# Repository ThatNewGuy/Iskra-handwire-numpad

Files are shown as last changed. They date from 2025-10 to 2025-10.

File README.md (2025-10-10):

## Iskra Handwired Numpad

### Overview
Iskra is a DIY 10‑key hand‑wired macropad designed for both wired USB and Bluetooth (ZMK) use. It uses low‑profile Kailh Choc switches and a Pro Micro nRF52840 (nice!nano v2 clone). The design is fully open source and supports ZMK Studio for easy keymap customization.

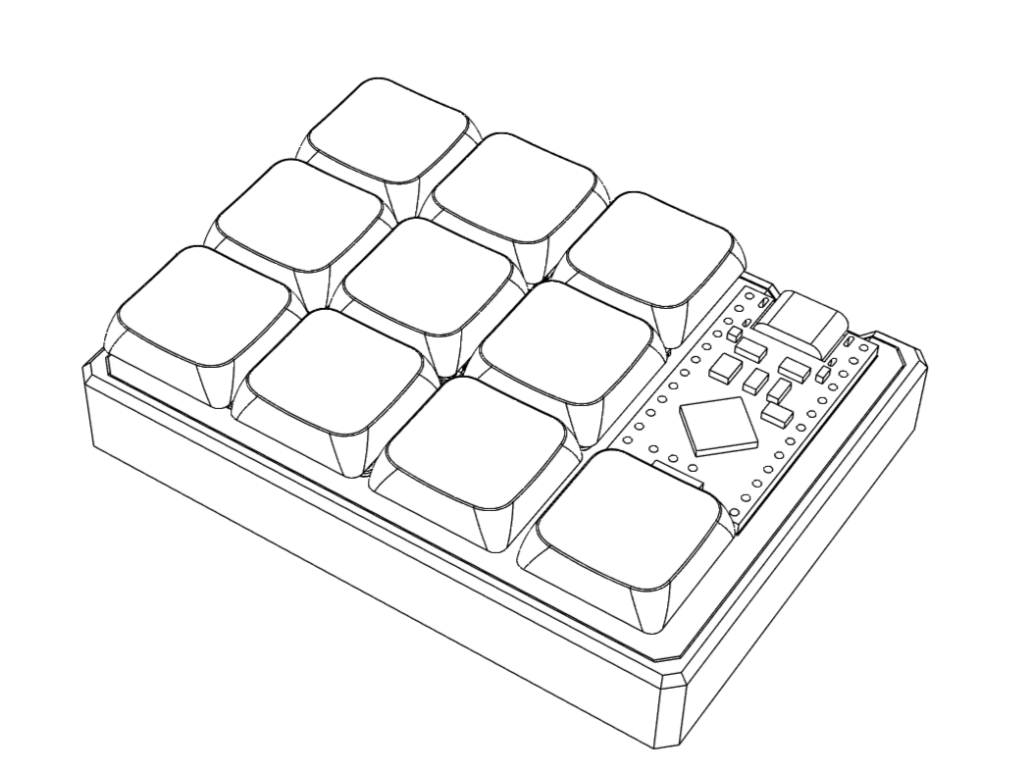
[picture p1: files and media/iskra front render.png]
Front render


#### Key features
- **3 programmable layers** (ZMK firmware)
- **Compact** credit‑card size layout (approx. 82 × 60 × 22 mm)
- **Hand‑wired** 3×4 matrix with 1N4148 diodes (10 keys populated)
- **Wired USB‑C** and **Bluetooth** modes
- **ZMK Studio** support for on‑device editing

### Real photos
<p>
  Home view
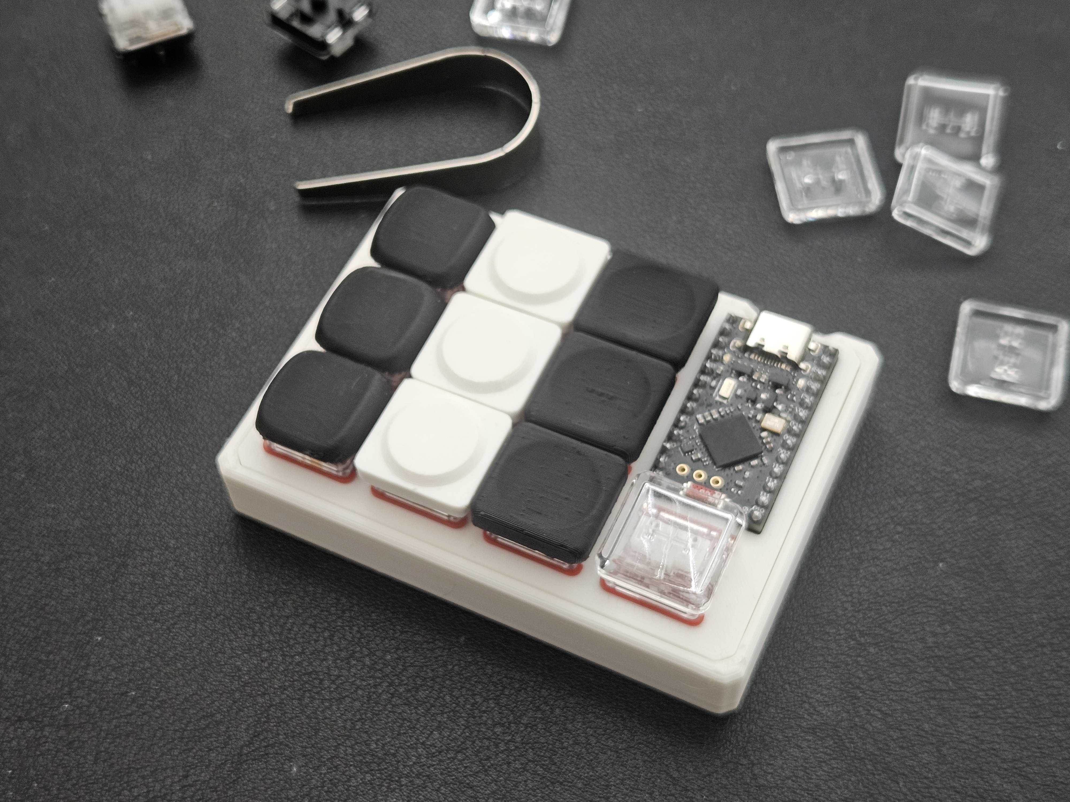
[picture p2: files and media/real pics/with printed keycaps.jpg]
With printed keycaps
  
</p>
<p>
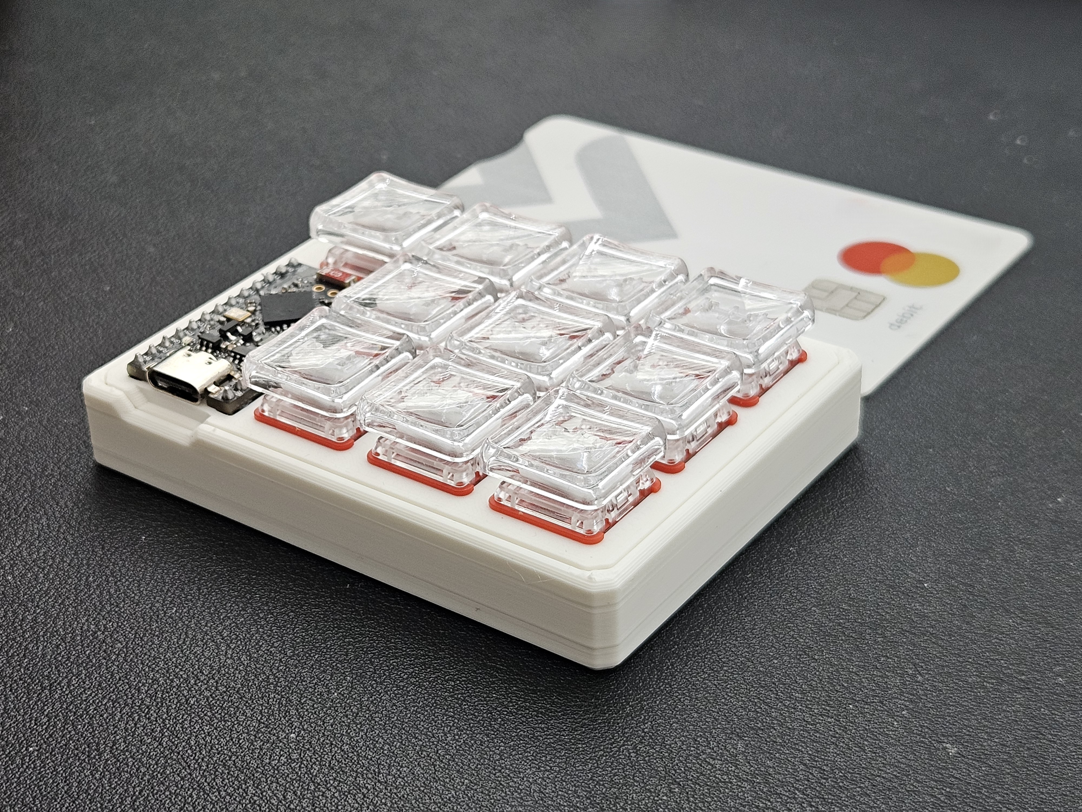
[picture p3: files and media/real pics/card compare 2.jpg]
Card compare 2
  
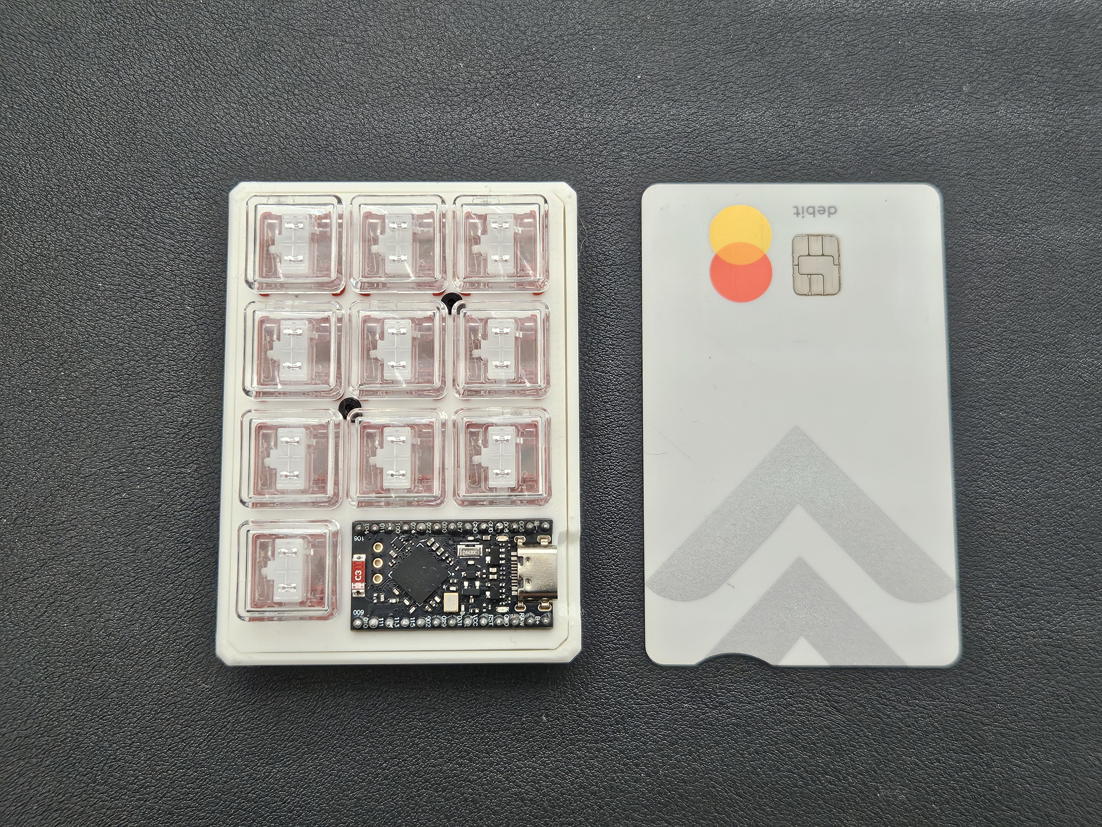
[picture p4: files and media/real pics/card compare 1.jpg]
Card compare 1
  
</p>

---

### Bill of Materials (BOM)

| Part | Qty | Price (EUR) | Link |
| --- | ---: | ---: | --- |
| Kailh Choc switches | 10 | 2.00 | [AliExpress](https://www.aliexpress.com/item/1005006626760418.html) |
| Pro Micro nRF52840 (nice!nano clone) | 1 | 3.80 | [AliExpress](https://www.aliexpress.com/item/1005007010555229.html) |
| M2 brass standoff, 6 mm | 2 | 0.20 | [AliExpress](https://www.aliexpress.com/item/1005006049595637.html) |
| M2 screw, 6 mm | 4 | 0.10 | [AliExpress](https://www.aliexpress.com/item/1005005070119421.html) |
| 1N4148 diodes | 10 | 0.13 | [AliExpress](https://www.aliexpress.com/item/1005006861038367.html) |
| Copper wire | 15 cm | 0.05 | [AliExpress](https://www.aliexpress.com/item/1005009078359338.html) |

Assumes you already have a soldering iron, solder, insulation/masking tape, and a few wires.

---

### Firmware
- Prebuilt firmware (drag‑and‑drop): `Firmware/Ready to flash firmware/iskra.uf2`
- Config source (ZMK): `Firmware/zmk-config-iskra`

#### How to flash (UF2)
1. Connect the numpad to the PC.
2. Short the `GND` and `RST` pins twice quickly (double‑tap reset).
3. A removable drive (e.g. “NICE NANO”) will appear.
4. Copy `iskra.uf2` into the drive.
5. It will restart; the numpad is now flashed.

Note: The prebuilt firmware assumes the same controller (nRF52840 nice!nano v2‑compatible) and the pin wiring specified below.

---

### Documentation
- [Build and wiring guide (PDF)](files%20and%20media/Iskra%20Numpad%20Build%20and%20wiring%20guide.pdf)
- [User manual (PDF)](files%20and%20media/Iskra%20Numpad,%20user%20manual.pdf)

 These documents provide a step‑by‑step reference for building a hand‑wired numpad: keyboard matrix wiring with **1N4148 diodes**, **Kailh Choc** low‑profile switches, and a **Pro Micro nRF52840** (nice!nano v2 clone). Topics include routing rows and columns, insulating wires to avoid shorts, mapping pins to firmware, flashing ZMK via **UF2**, configuring **Bluetooth** profiles, and using **ZMK Studio** to adjust keymaps.

---

### Layout, Layers, and Combos

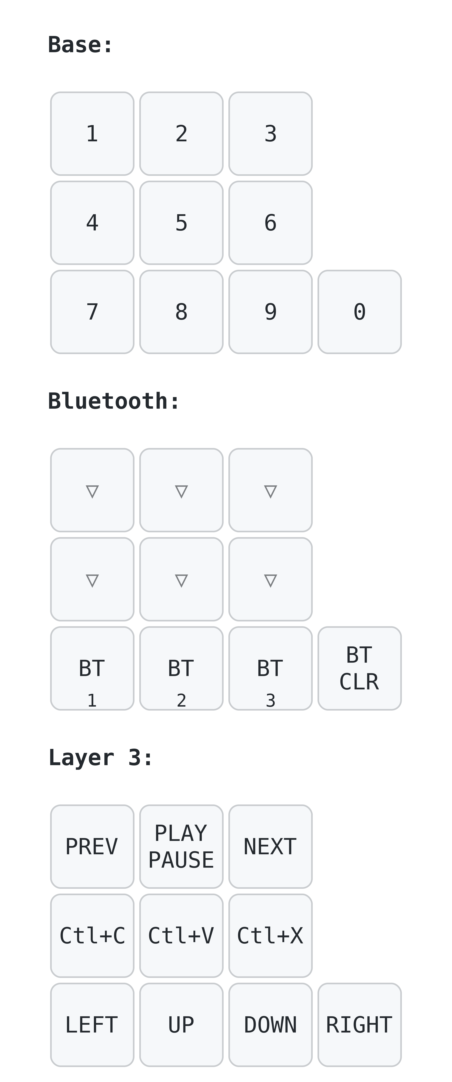
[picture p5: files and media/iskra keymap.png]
Keymap


#### Layers (from firmware config)
- **Base**: `1 2 3 / 4 5 6 / 7 8 9 0`
- **Bluetooth**: Bottom row provides Bluetooth controls — `BT_SEL 1`, `BT_SEL 2`, `BT_SEL 3`, `BT_CLR`; other keys are transparent.
- **Layer 3**: Media and navigation
  - Top row: Previous, Play/Pause, Next
  - Middle row: Ctrl+C, Ctrl+V, Ctrl+X
  - Bottom row: Arrow Left, Up, Down, Right

#### Combos
- **Base layer combo**: Press the top three keys at the same time → switches to Base
- **Bluetooth layer combo**: Press the middle three keys at the same time → switches to Bluetooth
- **Third layer combo**: Press the bottom three keys at the same time → switches to Layer 3
- **ZMK Studio unlock**: Press the top two keys at the same time

Combo visuals:

<p>
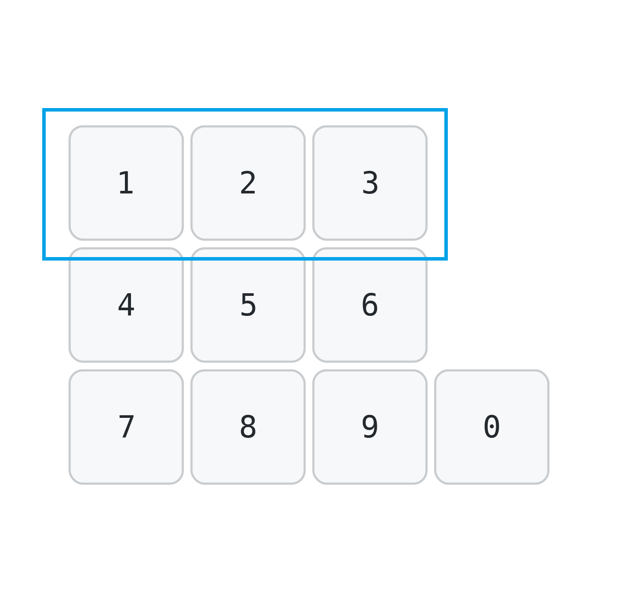
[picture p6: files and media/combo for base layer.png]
Combo for base layer
  
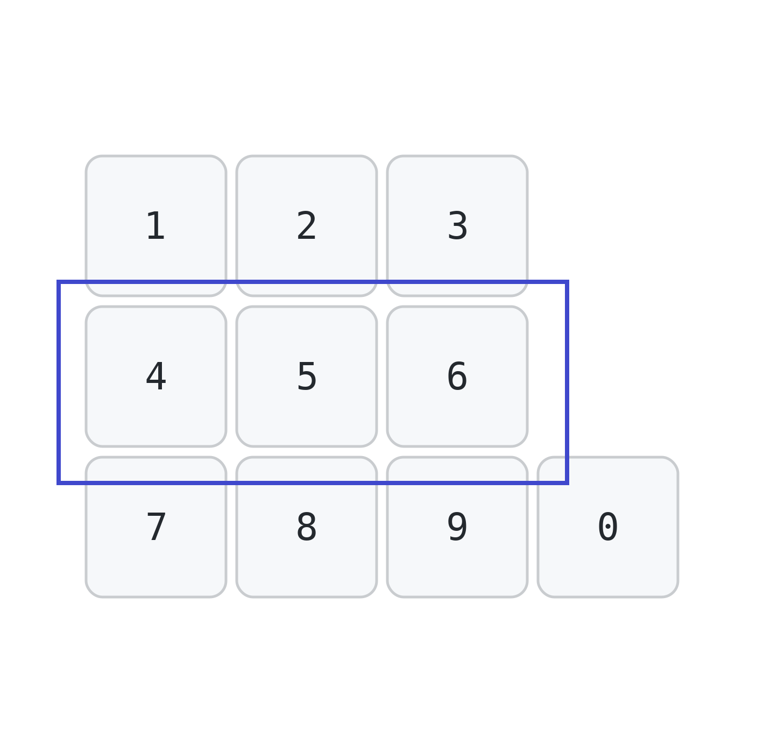
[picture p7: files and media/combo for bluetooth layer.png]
Combo for Bluetooth layer
  
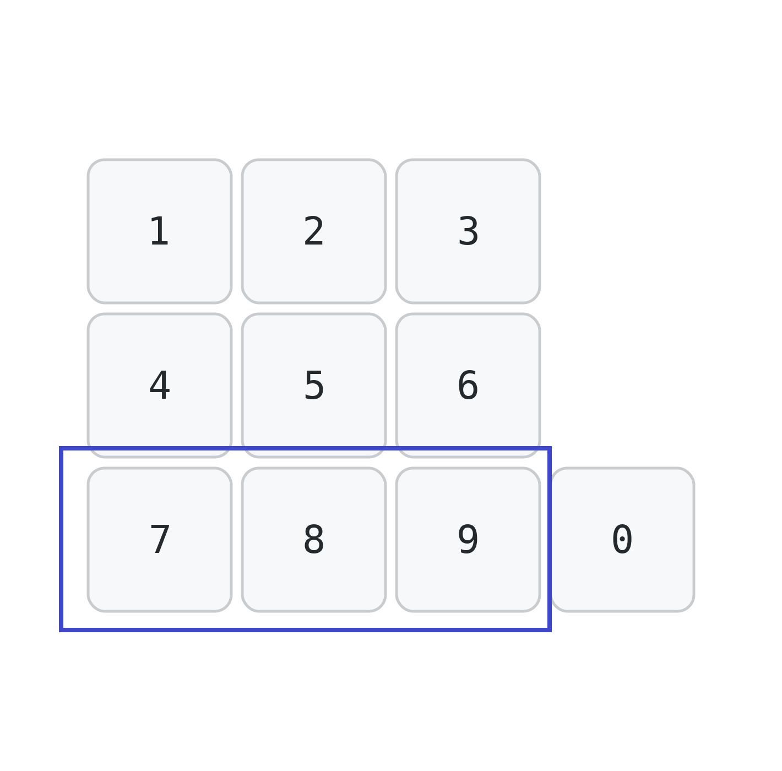
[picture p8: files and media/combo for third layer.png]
Combo for third layer
  
</p>

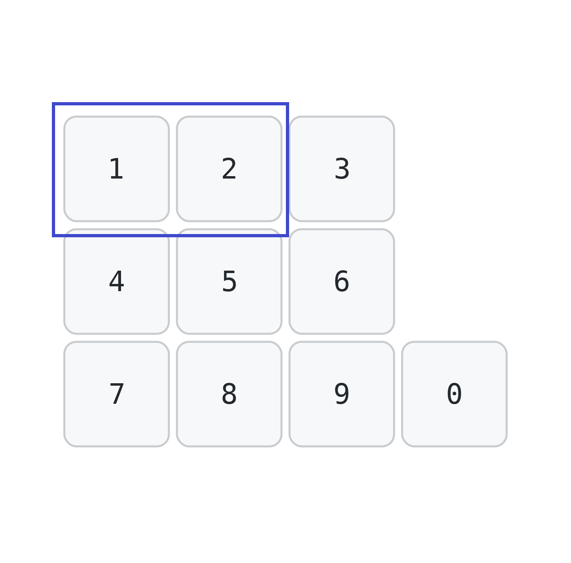
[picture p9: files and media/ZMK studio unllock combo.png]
ZMK Studio unlock combo


---

### Bluetooth usage
1. Power Iskra from a PC or power bank.
2. Use the **Bluetooth layer combo** (press the middle three keys simultaneously).
3. Select a Bluetooth profile using one of the bottom‑row keys: `BT1`, `BT2`, or `BT3`.
4. Pair from your device. The advertised name is “Iskra Numpad”.
5. To switch devices later, change the Bluetooth profile. Example: PC on BT1, phone on BT2.
6. Use **BT Clear** to forget the current profile.

---

### ZMK Studio and customization
- Use ZMK Studio on the web: `https://zmk.studio/` or download: `https://zmk.studio/download/`.
- Connect Iskra and select it in Studio.
- Press the **ZMK Studio unlock combo** (top two keys: 1 and 2).
- Edit and customize keys. Avoid removing the Bluetooth keys entirely (you can move them), or you may lose Bluetooth control.
- Save and exit.

---

#### Pin mapping (as used by the firmware)
- Rows
  - Top row → pin `100`
  - Middle row → pin `106`
  - Bottom row (with 4 keys) → pin `009`
- Columns
  - Column 1 (single key) → pin `010`
  - Column 2 → pin `104`
  - Column 3 → pin `113`
  - Column 4 → pin `002`

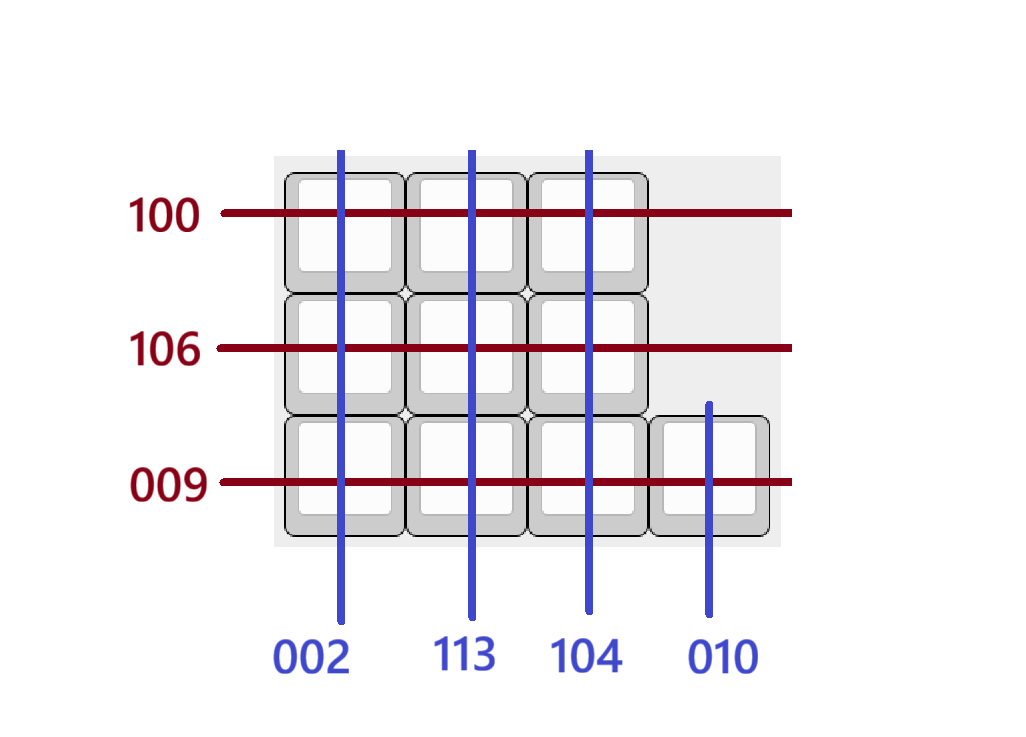
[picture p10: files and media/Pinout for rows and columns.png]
Pinout
Reference image: 

---

### CAD and print files
- Print‑ready 3MF: `Makerworld 3mf/Case ready to print.3mf`
- STEP models: `Step files/Case step.step`, `Step files/plate step.step`

Exploded view:

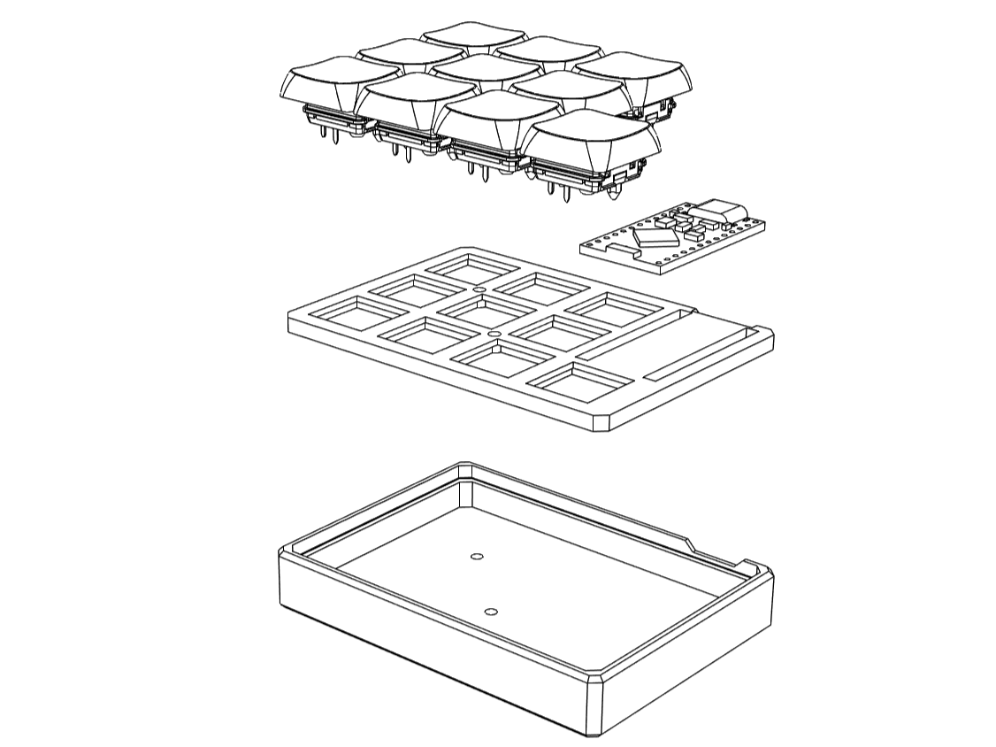
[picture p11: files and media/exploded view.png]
Exploded view


---

### License
Open‑source hardware and firmware.

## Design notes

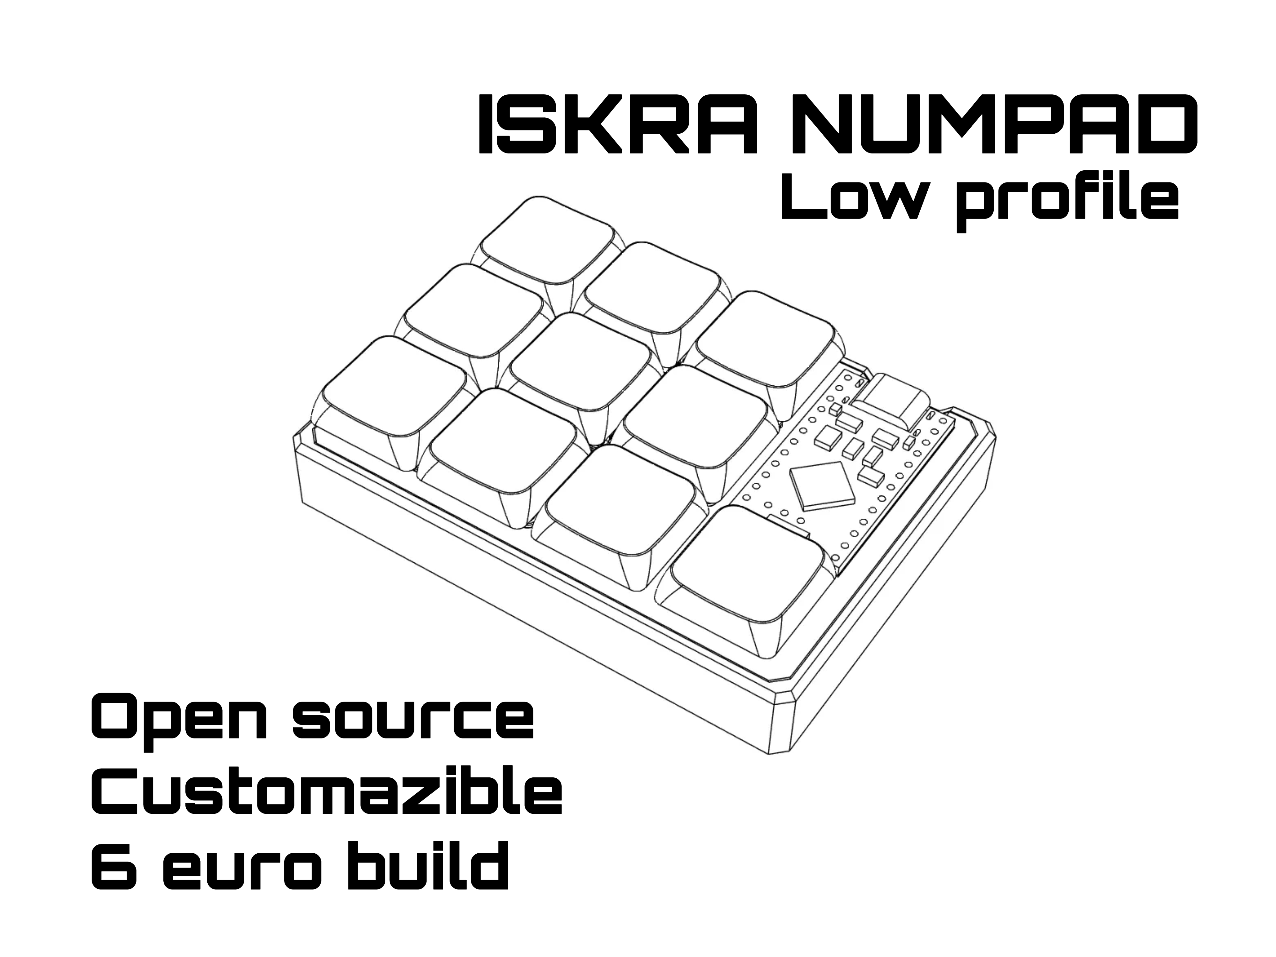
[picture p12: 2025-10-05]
files and media/4x3.jpg

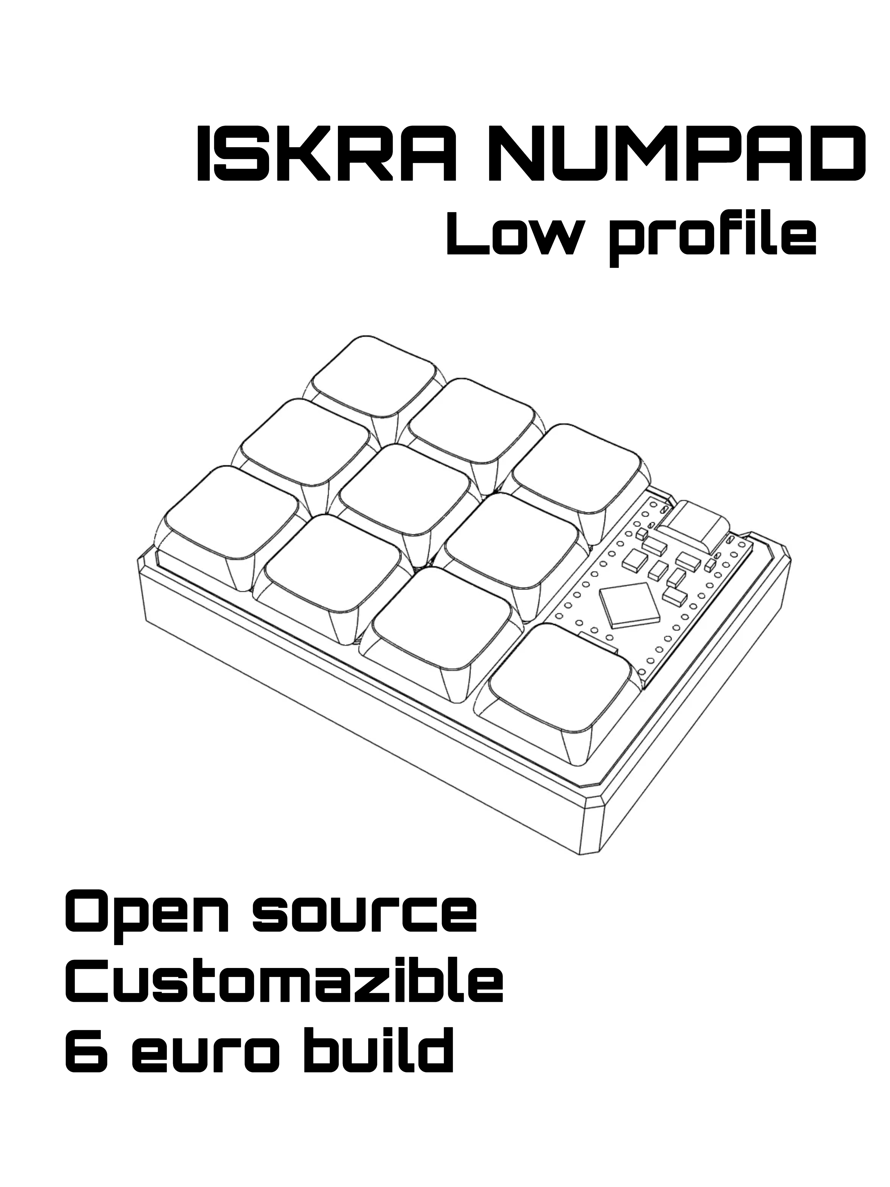
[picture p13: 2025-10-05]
files and media/3x4.jpg

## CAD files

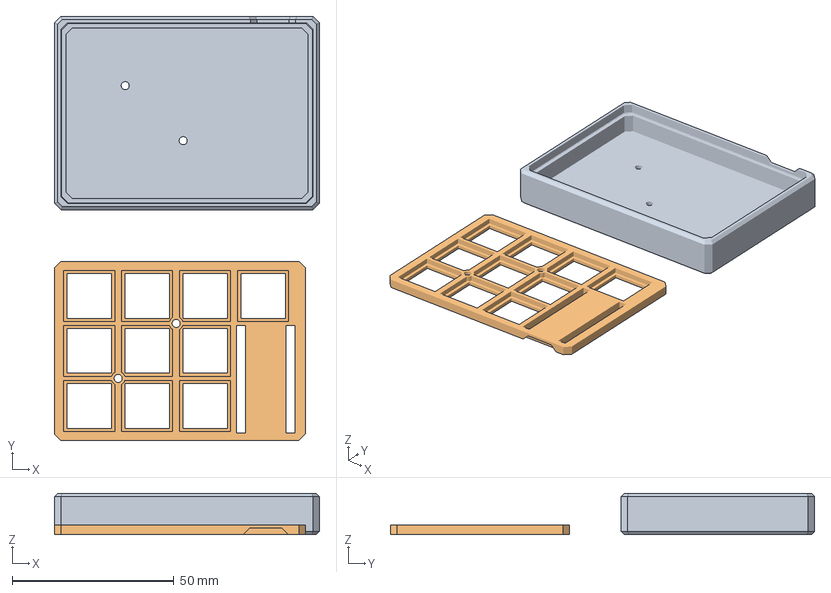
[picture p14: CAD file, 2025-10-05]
Makerworld 3mf/Case ready to print.3mf
81.9 x 131.1 x 12.8 mm
case
plate

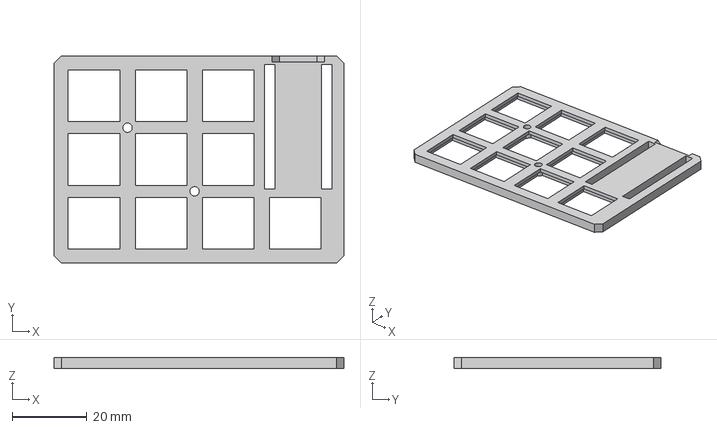
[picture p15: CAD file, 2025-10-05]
Step files/plate step.step
77.5 x 55.4 x 3.00 mm

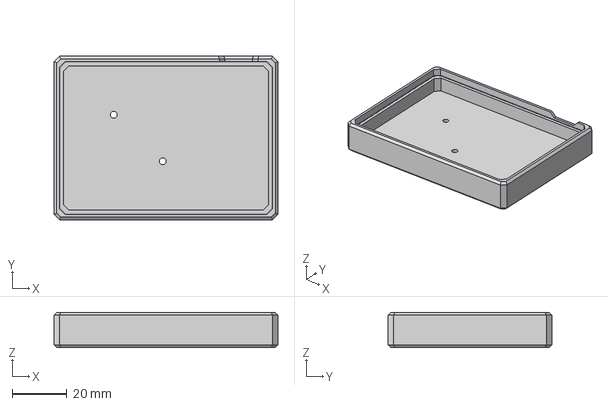
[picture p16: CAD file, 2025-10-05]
Step files/Case step.step
81.9 x 59.8 x 12.8 mm

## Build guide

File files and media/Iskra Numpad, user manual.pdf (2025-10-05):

# Iskra Numpad

# Guide and user manual

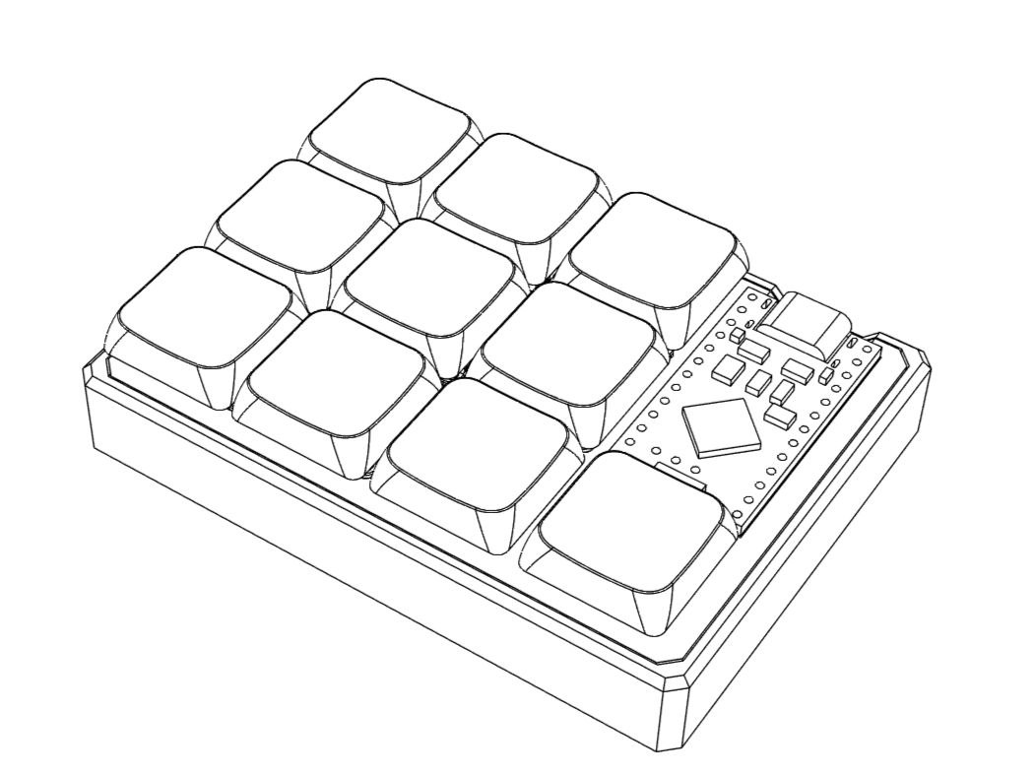
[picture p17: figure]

# Features

Iskra is a compact 10-key numpad with a footprint of 82 × 60 mm and a total height of just 22 mm.

It uses low-profile Kailh Choc switches, powered by a Pro Micro nRF52840 (nice!nano v2 clone) and supports both wired and Bluetooth operation.

It’s designed primarily for wired use over USB-C, but when powered from a PC or power bank it can also function as a Bluetooth numpad.

The firmware is based on ZMK and is fully open source. Iskra supports ZMK Studio, allowing users to customize keymaps without manual compilation.

The design is fully hand-wired and open source, making it easy to build, modify, and adapt.

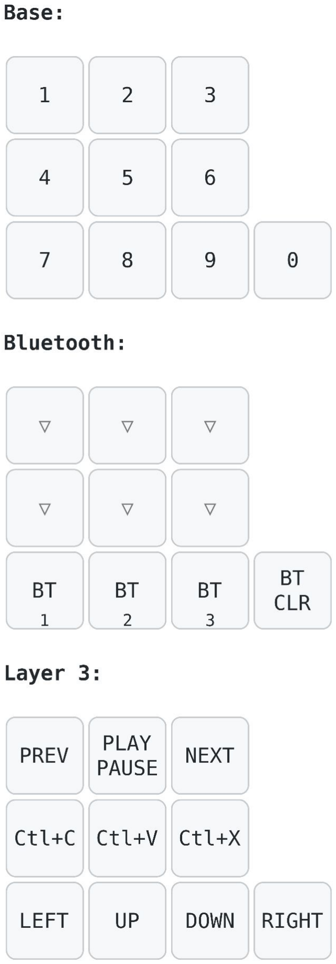
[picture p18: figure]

# Layout

Base layer: standard numpad layout.

Bluetooth layer: Bluetooth control keys and six blank keys for user customization.

Layer 3: preconfigured
shortcuts
- previous, play/pause,
next
- Ctrl+C, Ctrl+V, Ctrl+X
- Arrow keys.

# Combos

Combo for base layer

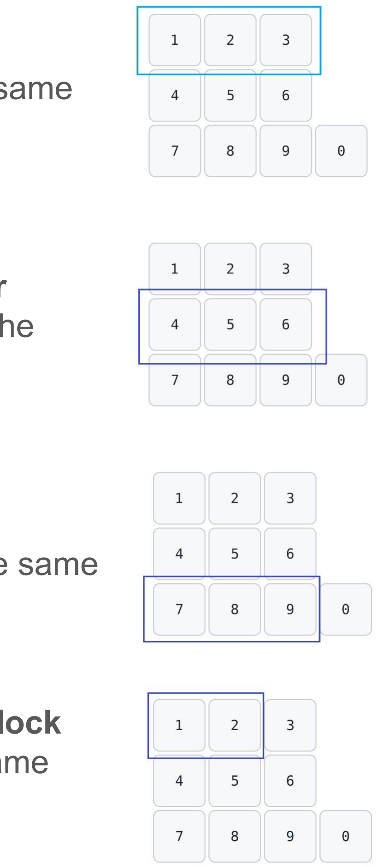
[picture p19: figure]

Press top three keys at the same time

Combo for Bluetooth layer
Press middle three keys at the same time

Combo for Third layer
Press top bottom keys at the same time

Combo for ZMK studio unlock Press top two keys at the same time

# How to use bluetooth

1. Connect Iskra to the power ( PC or powerbank) 2. Use combo to go to Bluetooth layer (three middle keys at the same time) 3. Press a key to select BT profile (you have 3 profiles to choose, you can add separate device to each profile) 4. Connect to the numpad via bluetooth, the name is “Iskra Numpad”

### The numpad will be accessible on that bluetooth profile, if you want to use it on other device, change the profile

### For example, PC is on BT1 and Phone is on BT2 Press BT Clear to “forget” and clear current profile

# ZMK studio and customization

- Use the zmk studio either via web on https://zmk.studio/ or download their firmware https://zmk.studio/download/ - Connect Iskra Numpad to the computer and select the numpad in the Studio - Press ZMK studio unlock combo (numpad key 1 and 2) - Edit and customize any key, but don't change the bluetooth keys ( you can change where they are, but don't remove them or you won't be able to use bluetooth) - Press save and exit

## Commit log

2025-10-05 chore: initial commit: firmware, media, docs
    [Case ready to print.3mf, Case step.step, plate step.step]
2025-10-05 fix: track zmk-config-iskra as files instead of submodule
